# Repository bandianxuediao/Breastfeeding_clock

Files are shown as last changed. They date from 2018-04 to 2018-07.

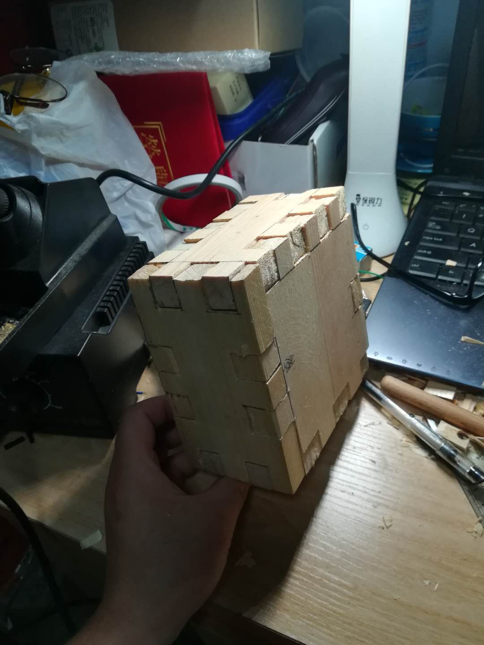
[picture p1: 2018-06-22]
DOC/Photos/15.jpg

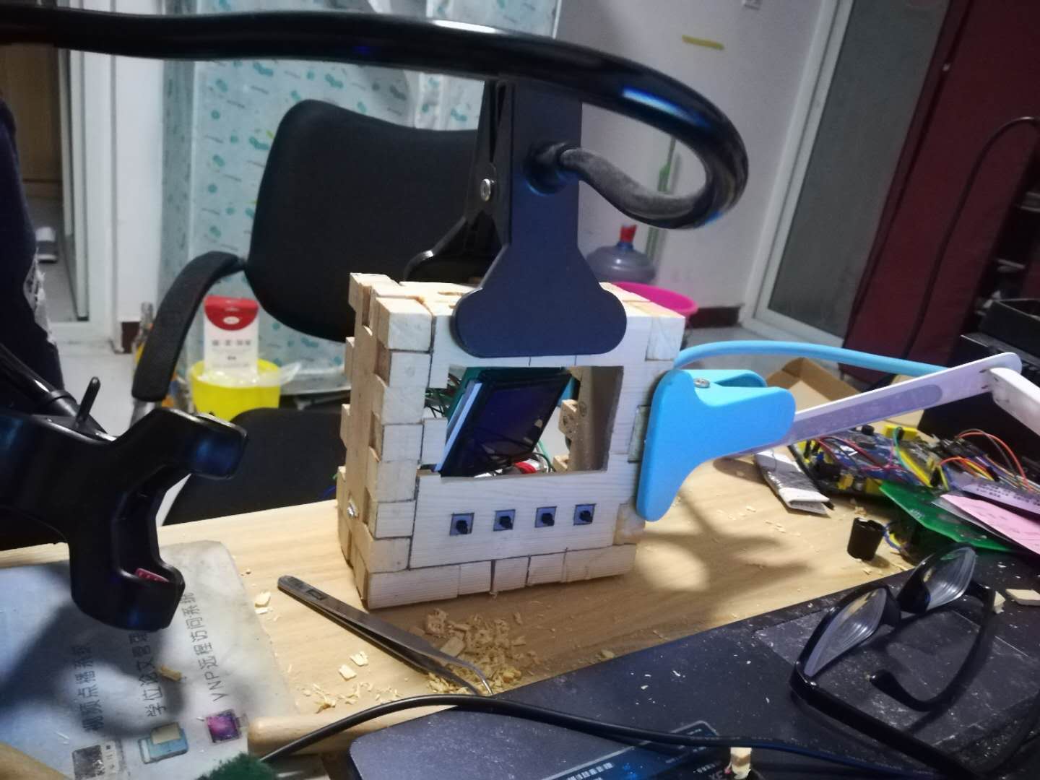
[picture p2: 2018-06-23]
DOC/Photos/10.jpg

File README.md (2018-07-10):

# Breastfeeding_clock<br/>
[开发过程记录](https://github.com/bandianxuediao/Breastfeeding_clock/blob/master/project_process.md)<br/>
详细的开发过程请点击上面的链接，或者直接访问project_process.md<br/>
更丰富的内容请访问我的个人网站[文禾每](http://www.wenhemei.com)<br/>
哺乳记录器，记录宝宝的哺乳时间，大小便时间、补水时间，以及距离上次相关事件的时间间隔。<br/>

## 项目背景
　　“丁酉年 冬月 癸巳日 卯时，爱妻诞下吾儿，重斤七整，性温良，状安详。及彼时新年初阳将醒，万物复苏。”这是我在2018年1月1日宝宝出生当天发表的朋友圈，而后妻子便开始了她照顾宝宝的忙碌生活。<br/>
　　数日之后，妻子提议：能不能做个软件来方便记录宝宝大小便和哺乳的时间。<br/>
　　本来想着只做一个android应用，方便随时使用手机来做记录、查看历史。后面我又觉得如果只做一个android应用的话之后就会被忘掉，随着时间的流逝什么也留不下来。干脆自己做一个实物的吧，于是便有了这个东西。<br/>
　　没有合适的工具，所有的隼都是使用雕刻刀一刀一刀刻出来的（还好当时买了较软的松木板，否则就不仅仅只是几个刀口几个水泡的事儿了）。<br/>
**通过这件事情算是真正的从心底里承认了一句话“不能随便评判别人的工作难易程度”。在预言阶段我仅仅是想拿几块木板用胶水粘起来，或者用钉子钉起来；采购物料期间看到淘宝推荐的雕刻刀，心想何不来几个卯榫，而且看起来也很简单。<br/>
实施阶段在我调整新打的PCB的时候我还在想着做个盒子也就一天的工作量。对，不出你们所料，做这个木盒子比画板子+写代码用的时间还长，而且还是如此的~不好看，"(￣▽￣)"""。<br/>**
　　从此项目的GitHub推进流程文档可以看出，项目建立时间是3月28日。中间还插入了其他的事情，不过6月总算是初步完成了。具体的项目推进流程可以在GitHub查看我的project_process.md文档。<br/>
## 项目介绍
　　简单介绍一下操作：<br/>
　　开机进入主界面后按下左按键进入项目列表，项目列表列出（哺乳、补水、小便、大便）项目；按上下键选择需要记录或查看的项目，按左键进入选中项目列表；列表中详细列出一共记录了多少条记录，距离上次记录过去了多少小时，按上下键翻页列表，按左按键增加一条当前时间的新记录（每个项目都有超时时间，在超时时间之内不允许再次存储此项目）。<br/>
　　主界面按下右按键可以进入时间设置的菜单，此处有时钟设置功能。同样是按上下键调整时间。<br/>
该记录器使用6000ma电池供电，红外对管检测物体靠近会点亮屏幕2分钟，其他任何按键均能触发1分钟倒计时重载。<br/>
## 硬件概述
　　硬件上面倒没什么复杂的：主控芯片使用的是STM32F103C8T6；12864的主控是ST7920；存储器使用了AT24CM01（1M位的EEPROM）；红外感应使用的是红外对管+LM393比较器。<br/>
### ST7920主控的12864<br/>
　　我这块12864不知道怎么回事，屏幕刷新几次就会出现乱码。之前用的同一批屏幕都没有这种情况，因为只剩下了一块，就只能先勉强用着。网上说可能驱动能力不足，于是加了上拉电阻4.7k-10k均没有效果；也有说时序不对，我是用逻辑分析仪抓的波形是没问题的；也有说在写屏幕的数据时没有控制好数据长度，这一条我还是有点赞同的，查了很久也没找到能出问题的地方，后边的项目结束后还的回头过来再解决一下。<br/>
　　原本怀疑的电源经过测试已经排除。  
　　乱码问题已经解决，是我之前已经遇到的但是却没引起我注意的一个bug。查出来之后才恍然大悟，我在RTC秒中断里面调用了屏幕刷新函数，而屏幕刷新函数里面有延时。所以**中断里面一定不能有延时**
### EEPROM的空间分配<br/>
#define INDEX_ADDR_LACTATION     10//哺乳索引存储地址<br/>
#define INDEX_ADDR_DRINK     20//补水索引存储地址<br/>
#define INDEX_ADDR_SHIT      30//大便索引存储地址<br/>
#define INDEX_ADDR_URINATE       40//小便索引存储地址<br/>
#define BASE_ADDR_LACTATION     100//哺乳存储的起始地址<br/>
#define BASE_ADDR_DRINK     30100//补水存储的起始地址<br/>
#define BASE_ADDR_SHIT      60100//大便存储的起始地址<br/>
#define BASE_ADDR_URINATE       90100//小便存储的起始地址<br/>
　　我的存储信息每条占用6个字节，假设每个项目每天存储6条，能够一直使用833天。如果以后有朋友需要定做的话可以更换flash来作为存储器，这样存个十几年是没问题的，^_^~~<br/>

### 红外感应<br/>
　　红外这块初步设计时准备使用热释电来做的，调试过程中发现热释电的感应范围太大了，远远超过了我的需求。经过吴哥的点拨，更换热释电为红外对管。直接淘宝5块钱包邮买了两个红外对管+LM393的模块，上机测试后完全符合我的预期效果，只是太阳光也对这东西有影响。以后如果还做的话这个也是一个需要着手解决的问题。<br/>

　　做板子的时候几个地方都是板子回来以后后期处理的，这些问题点我会在下一版本中修复。<br/>
　　V2完美版正在开发中……<br/>

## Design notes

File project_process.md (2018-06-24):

# Breastfeeding_clock<br/>
哺乳记录器，记录宝宝的哺乳时间，大小便时间、补水时间，以及距离上次相关事件的时间间隔。<br/>
# 开发过程记录

>2018年3月29日23:33<br/>
 >>使用储物柜的源代码，调通PA0-PA7作为12864的数据线；增加资料，主要是红外感应的资料；修改引脚分配表；DXP文件定义一些引脚。<br/>
 
>2018年3月31日23:00<br/>
>>关于电源这方面，之前没有做过电源的升压电路，也为安全考虑不敢轻易尝试。所以在淘宝购买了现成的充电宝的升压电路板，有过压过流保护，可以放心使用。<br/>
>>连接稳压电源时USB_5V负责给主板供电、给电池充电；<br/>
>>没有连接外部电源时，开关拨到电池供电端，此时就由电池给主板提供5V电源。<br/>
  
>2018年4月1日（补）<br/>
>>元件选择封装，错误检查，PCB布局。<br/>

>2018年4月2日23:30<br/>
>>修改部分元器件封装，修改原理图（将一些不确定，不需要插座的元件做成PIN1、空置引脚全部引出）<br/>
>>PB2(BOOT1)接地。<br/>
>>PCB电源布线、12864布线。<br/>

>2018年4月17日20：00<br/>
>>前面这段时间确定了PCB，并且打了样板。在老家焊接并初步调试完成。<br/>
>>之前准备采用热释电红外作为感应模组，通过对手头现成的热释电红外模块（BISS0001）的测试发现其感应范围太大，不适合做近距离的感应。<br/>
>>经同事点拨，红外对管似乎更适合我的需求。<br/>
>>使用明哥的寻迹小车上的红外对管测试之后发现确实能很好的满足我的需求，遂淘宝下单买了两个红外对管模块--抱愧一对红外对管，一个LM393比较器。<br/>

>2018年4月18日22：50
>>由于之前预留的micro usb接口需要飞线，并且暂时用不到串口下载功能，故没有使用CH340。今天将CH340电路中的一个NPN三极管的电路改造成了12864的背光电源开关，由单片机的PA15引脚控制。代码已经实现相关功能。等红外对管收到之后可以配合红外对管对12864的背光电源进行管理，达到降低功耗的目的。
>>这部分电路回头做在DXP里，第二版的时候再搞一下。

>2018年4月21日0：50（21日发现bug）
>>将正点原子的实时时钟相关代码移植过来，并进行相关测试。中间发现秒更新放在秒中断里面的话屏幕上会出现一些乱码，随着时间的推移会越来越多。网上不少人讲是时序的问题，但是我的12864驱动已经使用很长时间，所以不会存在时序不对的问题。单步测试后发现时间更新显示函数自带的屏幕刷新功能影响了显示，具体原因未知，屏蔽此函数内的屏幕刷新功能之后显示正常。<br/>
增加“查看”之后的二级界面（暂时不会MD的表格功能，回头补）<br/>

>2018年4月21日18:06
>>今日凌晨所调试的屏幕刷新出现乱码，是因为频繁的刷新导致的。遂将主循环中的刷新函数去掉，放在秒中断中进行刷新。<br/>
另,频繁刷新导致乱码的问题可能是因为ST7920相关引脚没有做外部上拉，导致单片机操作上拉速度跟不上，电压还没达到要求就已经开始进行数据传输，导致出频繁刷新出现乱码。【此问题可在下次打板时留下测试电路，以供验证本次猜测。】已经使用1K电阻验证，行不通。可能是电阻太小，导致电流过大，各管脚出现串联现象？未知，待验证。

>2018年4月22日23:32
>>今日对EEPROM空间的使用进行了划分，由于后面要更换更大的AT24CM01，所以给各个Item设置了一个Base_Address,后面只需要更改基地址就行。第五字节存储一个0x55，用作初始化判断；10、20、30、40起始位置之后的十个字节存储索引，实际只用两个字节存储当前已经存了几条信息。<br/>
      偏移计算：    索引信息X6(每条信息所占空间)+Base_Address【会做表的时候再来添加，信息都在笔记本上写着。】<br/>
>>今日还将流程走到显示列表的界面，发现有些之前没考虑到的问题。时间差的计算倒腾了一下午，各种伪代码写了三大页。晚饭后还是把之前的所有方案全部推翻了，三百多行的代码直接删掉。如果有运行速度更快、占用空间更小的方案出现，那之前的代码写的再漂亮也会在新方案出来的那一刻变成一堆一文不值的乱码。主要是因为之前考虑的不定因素太多了，导致代码不好编写。其实真是的需求、使用环境中并不会出现那些不定因素，因为其他代码也对不定因素进行了限制。<br/>

>2018年4月23日23:26
>>使用10K排阻上拉12864的数据线，经过测试还是有些效果的。回头功能完成之后再将其他引脚也使用10K电阻拉高，以提升其驱动能力。<br/>
再次推翻之前的时间差计算方式，使用一个基准时间，计算秒数来对比。省去计算负数的可能。

>2018年4月24日23:59
>>今天有点过头了，距离项目结束越来越近，人越显得兴奋。每个功能的逐步完善，均能够给自己带来极大的愉悦感。<br/>
完善时间差的计算函数、完善存储函数、编写列表刷新函数。***睡觉啦***

>2018年4月25日23:59
>>列表刷新函数功能有些混乱，未完成正常的列表移动显示功能。基础算法和指针的移动没有协调好，初步判断为指针在某一步的时候反向移动导致出现问题。反应在显示屏上是时间列表在某一步排序反了。**睡觉啦**

>2018年4月26日23:29
>>将AT24C02更换为AT24CM01,存储空间由16KB扩大为128KB。128KB=131072字节=0x20000字节。程序中的P0位就是最高的那半个字节2，启示表达起来就是0x19999右移16位之后的0x01，所以P0位只有两种状态，就是0和1.<br/>
准备再次奋战列表功能的时候发现屏幕突然暗了，测量之后发现电池电压只有2.4V了，充电几分钟之后变成2.58V。证明了电池的欠压保护还是起到了作用的，电池还能继续使用。功能模块完成以后可以考虑添加分压电阻，接上STM32引脚来测量电池电量。就这样了，收拾东西，明天晚上回家了。**睡觉啦**

>2018年5月4日
>>前面这些天回了趟老家，项目进展稍有延迟。<br/>
不过延迟并不代表没有什么都没有做，这期间将列表上下翻页的算法彻底的搞了一下，经过测试还算比较稳定的.<br/>
修改了计算时间差的一个小BUG，出现这个bug的原因是在计算时间差小数的时候忽略了秒计数的累加超过小时的情况，以至于会出现3600秒本来是1.0小时，结果计算为**1.10小时**这种情况。将小数位直接 %10就解决问题<br/>
对连续记录时间进行了限制，即在上次记录之后多长时间内不应该再次产生该事件的防错机制。<br/>
初步设定的时间:<br/>
哺乳：1小时<br/>
补水：1小时<br/>
小便：0.5小时<br/>
大便：1小时<br/>
这个时间我本来是给每一个事件设定了一个计数器，后来实际Debug过程中发现直接拿前面算好的时间差是更方便的。所以一个项目中如果不去认真考虑的话会产生很多垃圾代码，上位机体现可能不是很明显，但嵌入式开发过程中就会出现各种问题，最常见的就是存储空间不够了，垃圾代码过多，僵尸代码不及时处理会拖慢系统的运行效率，也给阅读代码的人带来很大的阻碍。**严格审查代码**切记切记！<br/>
4号这天将红外对管控制显示屏背光的相关代码进行了添加。<br/>
具体功能为：<br/>
1、开机背光亮起2分钟<br/>
2、任何按键都能唤醒背光2分钟<br/>
3、红外触发背光亮起2分钟<br/>
启示我考虑的是将12864的主电源也接在一起，这两天将代码完善之后可以实际测试一下。<br/>
另外12864来回按键出现乱码的问题依然存在，这是一个遗留的大问题，后面还需要尝试各种操作：重新焊线，热熔胶固定焊接头等等....<br/>

>2018年5月6日 19:33
>>从昨天一直到现在中间基本上把程序固定了，昨晚开始弄直隼。下手之前觉得没什么，可一旦开始动手便感觉到了困难。所以说各行各业都有各自的运行轨迹，不能再没有任何尝试抑或浅尝之后便断定这东西很简单，很好搞。实际动手操作过才能下结论。好了不写了，得抓紧时间干活了，这两天我才吃了两顿饭。一直觉得时间不够用，恨不得一天二十四小时都在干活。刚刚短信提示TTP229的板子快递到了，待会明哥回来吃过饭后把板子焊接完毕再睡觉咯。

>2018年5月25日
>>前面这段时间一直在弄木盒子，越弄越发现真不不好搞。今天上班时想到了屏幕乱码是不是电源引起的呢？经过给显示屏单独供电测试之后发现问题不在电源。所以后面还是得把寻找问题的重点放在屏幕底层驱动上面～

>2018年6月6日23:16
>>今天发现是RTC秒中断里面的SHOWTIME函数导致出现乱码的，一瞬间想起来之前也发现了这个问题，但是没有引起我的重视。今天仔细一想，还真是这里的问题。因为showtime函数里面有屏幕刷新函数，而屏幕刷新函数里面又带有延时函数。在中断里面调用延时函数是一大忌讳，我已经在这上面吃了几次亏了。虽然这次只有几微秒的延时，但还是搞得自己差点崩溃，不过好在最后的最后还是被细心的我找到了问题所在（hiahiahiahia^_^）。</br>

>>其实，把刷新函数放在住循环里面处理的话也有问题。就是每一个秒中断不能及时的被显示出来。这就会导致在主界面上面看到秒计数一会儿快一会儿慢。</br>
>>一个问题解决之后就得想着另一个问题了，一个是主界面秒计数（这个不解决也行，优先级靠后）；在一个就是电量消耗的问题。今天更新的版本中我已经

将屏幕持续点亮的时间从两分钟降低到了1分钟，以此来节约电量。再者再完善过列表显示的逻辑之后再继续测试功耗的大小。说到列表显示就再多说几句，列

表显示之前是已经测试过没问题了的，这两天发现还是有一点小bug的，不知道是代码没有保存还是怎么的。明天再详细的看一下吧。**睡觉了，安安**

>2018年6月7日22:36
>>昨天发现列表显示还是有点问题，今天查了下代码发现一点bug，修改之后初步测试通过。

>2018年6月11日00:36
>>测试了功耗，将万用表串联在升压电路之后到主板之间的线路上测得：屏幕亮起的时候124.8mA；屏幕灭掉的时候74mA。升压电路还有损耗，所以估算使用时长约为60H.
>>精修木盒，将不平整的契合部分使用木挫修平整，使用木屑填充小缝隙，木片填充大缝隙，使用502固定，等待502干了之后再挫一遍。

>2018年6月15日 23:33
>>今天使用小型平锉将契合部分锉了一下，然后发到木工论坛。有师傅说还可以继续打磨，抛光一下。</br>

>2018年6月17日 23:45
>>今天使用吊磨，套上80目的砂带狠狠地打磨了一下。将之前开的榫的差距给补了一点，看起来不是坑坑洼洼的了。木板厚一些还是有好处的，这次差不多磨掉了3mm左右。明天是用砂纸稍微抛光一下看看。</br>

>2018年6月18日
>使用砂纸打磨到1000目，时间比较紧，没有继续打磨。网上买了蜂蜡也没到，所以暂时没有烫蜡。

>2018年6月21日
>>功能补全，因为之前测试的时候一直都是拿哺乳这一项来进行的，其他项没有相关的流程代码，今天把其他三项的流程代码添加了上来。并且在菜单项里面添加了清空的功能，经过初步测试是没有什么问题的。

>2018年6月24日
>>今天把屏幕持续点亮时间从之前限定的2分钟缩短为1分钟了，省电为主。况且任何操作都会重置倒计时，所以不用担心操作时间不够的问题。</br>

##到此为止，此项目基本完结。后面如果再有更新也只是日志文档的完整，与项目具体内容无关。</br>
　　　　　　　　　　　　　　　　　　　　　　　　　　　　　——2018年6月24日   李亚东

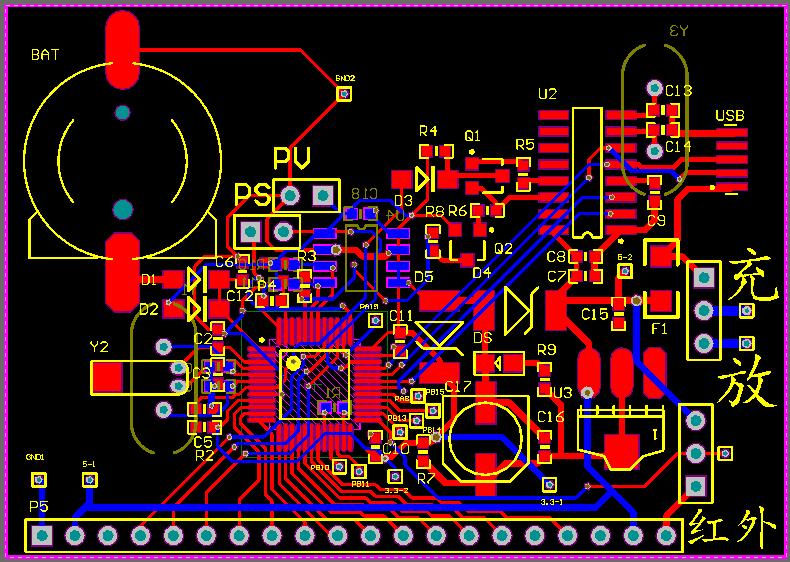
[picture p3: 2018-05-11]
DOC/Photos/PCB.jpg

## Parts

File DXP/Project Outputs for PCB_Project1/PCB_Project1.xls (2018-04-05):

Comment | Designator | Footprint | Quantity
BATT | BAT | BATM | 1
22P | C1, C2, C3, C4, C13, C14 | 0603p | 6
104 | C5, C7, C9, C10, C11, C12, C15, C16, C18，'C6 | 0603p | 9
10uF | C8 | 0603p | 1
220uF | C17 | CC6.56.5 | 1
1N4148 | D1, D2, D3 | DIODE_SOP | 3
SMBJ5.0A | D4, D5 | SMBJ | 2
LED1 | DS | SMDLED | 1
1000mA | F1 | 1206 | 1
OLED | P5 | HDR1X20 | 1
S8050 | Q1 | SOT-23R | 1
S8550 | Q2 | SOT-23R | 1
0 | R1, R7 | 0603p | 2
10K | R2, R3, R4 | 0603p | 3
1K | R5, R6, R8 | 0603p | 3
510 | R9 | 0603p | 1
4.7K | R10, R11 | 0603P | 2
STM32F103CBT6 | U1 | LQFP48_M | 1
CH340G | U2 | SOP16M | 1
AMS1117-3.3 | U3 | AMS1117 | 1
24C02 | U4 | SOP-8 | 1
USB | USB | USB/SM0.8-6H5 | 1
8M | Y1 | XTAL_US | 1
32.768K | Y2 | XTAL32 | 1
12MHz | Y3 | XTAL_US | 1

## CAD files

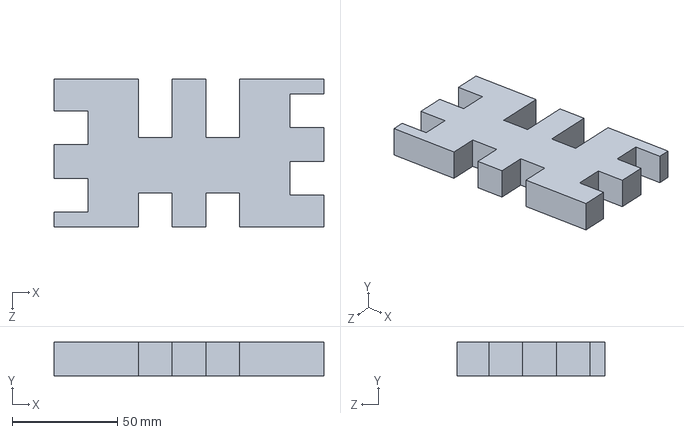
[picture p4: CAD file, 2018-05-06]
DOC/SOLIDWORKS/零件3.SLDPRT
128.0 x 16.0 x 70.0 mm

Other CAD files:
DOC/SOLIDWORKS/零件1.SLDPRT
DOC/SOLIDWORKS/零件2.SLDPRT

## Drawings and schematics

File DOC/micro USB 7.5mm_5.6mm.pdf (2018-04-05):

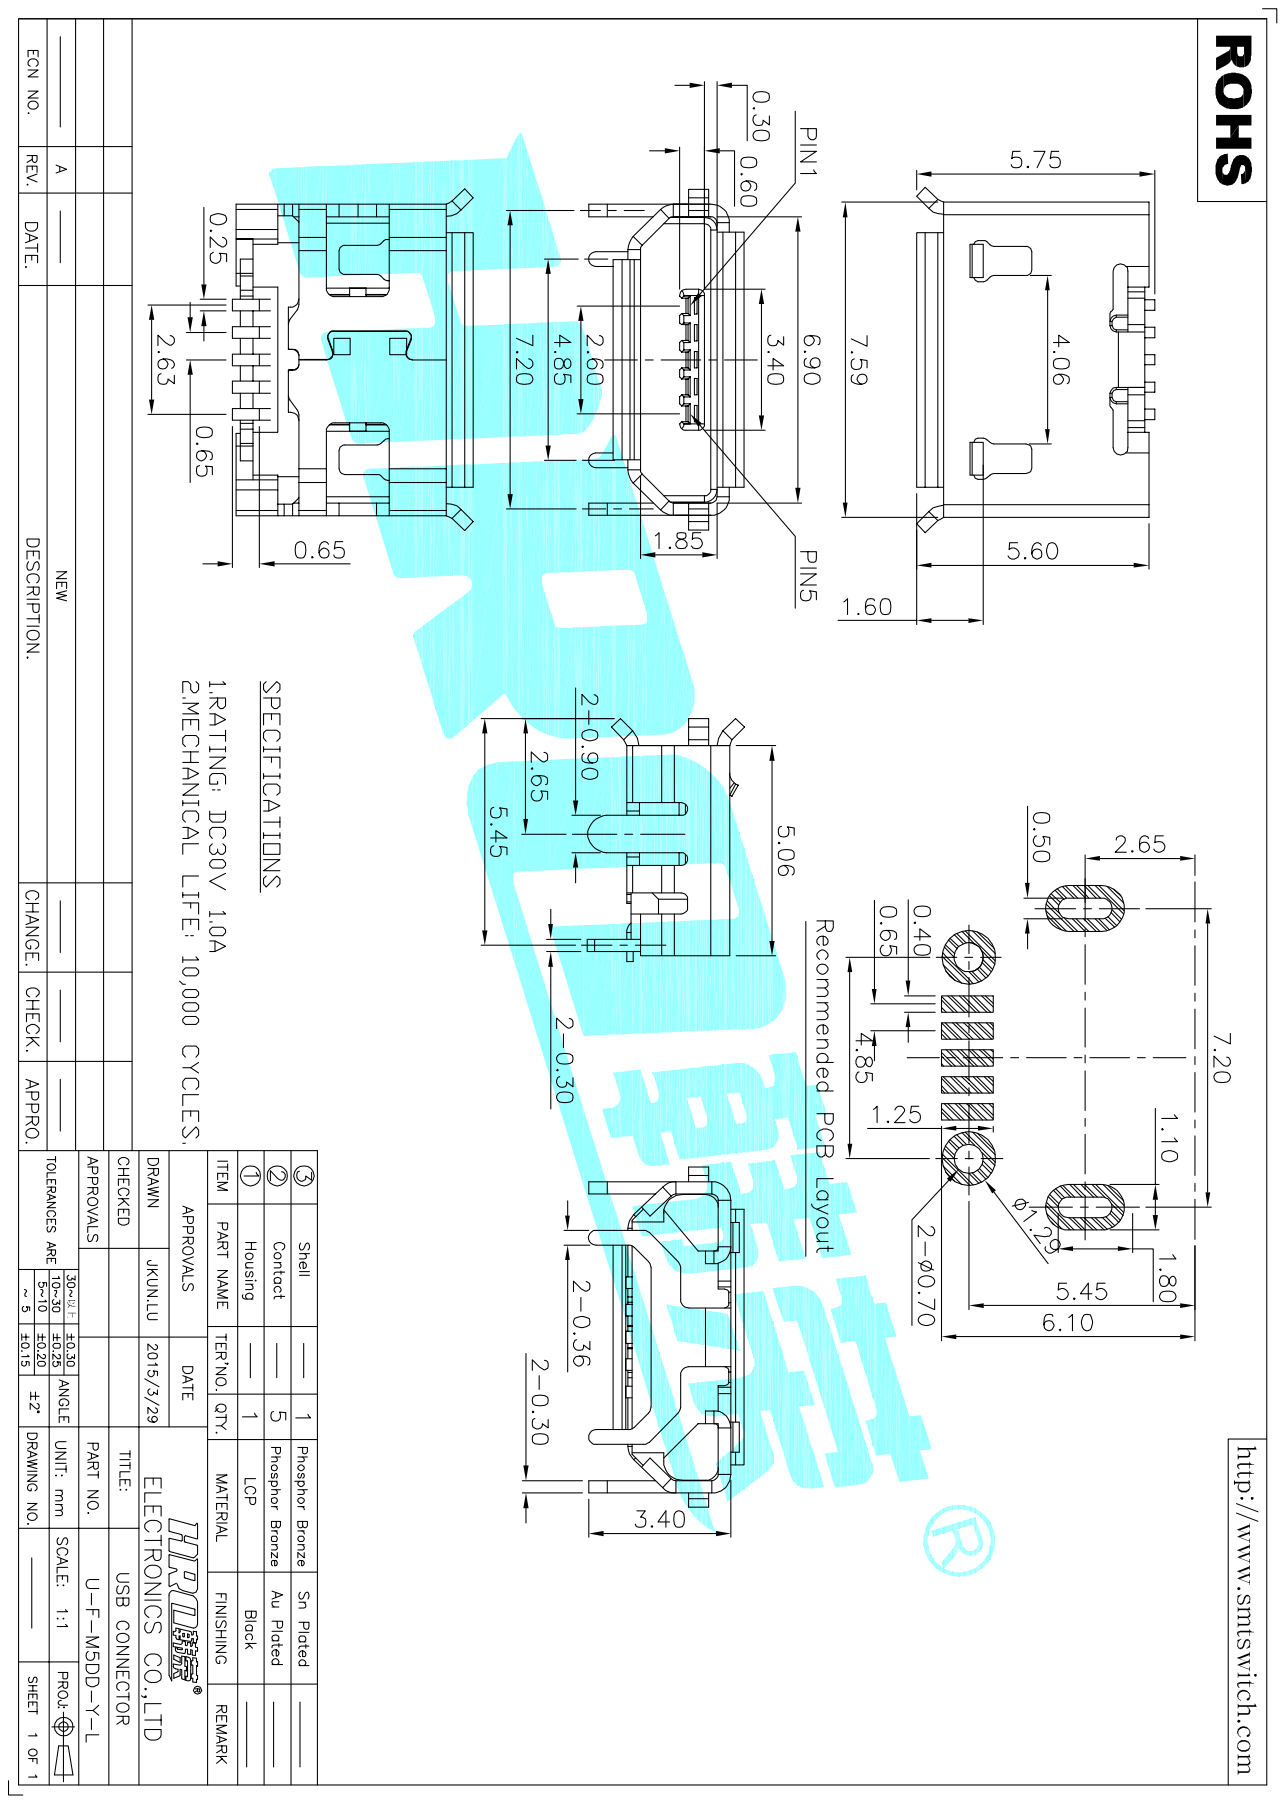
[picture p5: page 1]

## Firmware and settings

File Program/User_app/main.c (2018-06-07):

#include "includes.h"
SYS_STATE Current_state;
SYS_STATE KEY_state;
int main(void)
{
	u8 temp = 0;
	u8 read_temp1[6];
	//  NVIC_SetVectorTable(NVIC_VectTab_FLASH, 0x20000); //与配置文件相对应  配置程序的起始地址，前面一部分留给了bootload
	NVIC_PriorityGroupConfig(NVIC_PriorityGroup_2); //设置NVIC中断分组2:2位抢占优先级，2位响应优先级

	SysTickInit();         //设置滴答定时器中断时间为1ms

	EE_IIC_Init();             //EEPROM的IIC初始化

	RCC_APB2PeriphClockCmd(RCC_APB2Periph_AFIO, ENABLE);
	GPIO_PinRemapConfig(GPIO_Remap_SWJ_JTAGDisable, ENABLE);        //使用了spi3，禁用JATG，保留SWD功能

	PIN_Init();

	lcd12864_init();//12864初始化
	RTC_Init();
	ShowWelcome();
	delay_ms(600);
	Back_Light(1);//开机背光电源输出5V
	SetLightTimer(60000);//设置背光亮起时间1分钟
	Current_state = WELCOME_WAIT;



	//  Back_Light(0);
	//RTC_Set(2018, 4, 24, 23, 26, 30); //设置时间
	//          AT24CXX_WriteLenByte(10, 0,2);
	//          AT24CXX_WriteLenByte(20, 0,2);
	//          AT24CXX_WriteLenByte(30,0, 2);
	//          AT24CXX_WriteLenByte(40,0, 2);



	oled_updatescr(0, 64);//屏幕刷新

	//  //测试一下，一直刷新屏幕，清空缓存是否还会出现乱码现象
	//  while(1)
	//  {
	//

	//          oled_updatescr(0, 64);     //屏幕刷新
	//      delay_ms(10);

	//  }



	while(1)
	{
		Detect_Pin_State();

		if(GetLightTimerState() == TIME_OUT)
		{
			Back_Light(0);//背光电源关闭输出5V
		}

		White_Line();

		//      if(max_waite==10000)
		//      {   lcdreset();                    //初始化LCD屏
		//              clrgdram();
		//              max_waite=0;
		//      }

		oled_updatescr(0, 64);       //屏幕刷新
	}
}

/************* The End ! *****************/

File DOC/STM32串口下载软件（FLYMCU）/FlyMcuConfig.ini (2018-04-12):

[Comm]
Port=-1
PortBps=0
[FileSetting]
chkbReloadFile=1
FileName=D:\LYD\WorkSpace\GitHub\Breastfeeding_clock\Program\USER\obj\cabinet.hex
PageControl1Index=1
N2Checked=1
language=0
[LPCSetting]
LastSuccessBps=460800
OscFreq=20000
rgLpcEraseAllBlock=1
rgLpc1FC=0
cbISPEN_WDT=0
[STMSetting]
cbSTMExecAfterFlash=1
cbVerify=1
cbRtsDtrUsage->ItemIndex=3
MenuUseEagleComm=0
menuBeepEnable=0
menuEnableHighBps=0
menuUseRamIsp=0
cbAutoProgram=0
cbSTMWriteOption=0
STMOptionBytes=A5FFFFFFFFFFFFFF
STM32F2_F4OptionBytes=AAFFFFF
[FormWindow]
WindowState=0
WindowXDPI=96
WindowYDPI=96
WindowClientHeight96=373
WindowClientWidth96=680
WindowLeft96=353
WindowTop96=139
[fmSerialNoSetting]
cbUseID=0
medAddress=0x08000000
medLength=16
medInit=4
medIncLen=1
rgEndian=0
rgSnInFlashOrEeprom=0
cbSerialNoFormat=0
[fmSerialization]
cbEnableSerialization=0
edMcuIspDllFileName=
[fmProgCount]
medProgCount=0
[fmMSP430Settings]
orgVecs=FFFFFFFFFFFFFFFFFFFFFFFFFFFFFFFFFFFFFFFFFFFFFFFFFFFFFFFFFFFFFFFF
Vecs=FFFFFFFFFFFFFFFFFFFFFFFFFFFFFFFFFFFFFFFFFFFFFFFFFFFFFFFFFFFFFFFFFFFFFFFFFFFFFFFFFFFFFFFFFFFFFFFFFFFFFFFFFFFFFFFFFFFFFFFFFFFFFFFF
BSLKeys=FFFFFFFFFFFFFFFFFFFFFFFFFFFFFFFFFFFFFFFFFFFFFFFFFFFFFFFFFFFFFFFFFFFFFFFFFFFFFFFFFFFFFFFFFFFFFFFFFFFFFFFFFFFFFFFFFFFFFFFFFFFFFFFFFFFFFFFFFFFFFFFFFFFFFFFFFFFFFFFFFFFFFFFFFFFFFFFFFFFFFFFFFFFFFFFF
PortSettings=1
MiscSettings=0
cbEnableAdvanceVectorModify=0

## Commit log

2018-03-28 创建DXP文件
    原理图基本完成，还差按键没有添加，功能引脚未完全分配。
    [PCB1.PcbDoc, PCB_Project1.PrjPCB, Sheet1.SchDoc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]
2018-03-28 doc
    引脚分配表
    [IO引脚分配表.xlsx]
2018-03-29 网络搜集ST7920例程
    以前用的ST7920驱动部分代码使用寄存器操作，显得有些混乱。从网上查找的例程，代码看起来比较正规，等待回家测试合并~~
2018-03-29 变更源代码
    使用储物柜的源代码，调通PA0-PA7作为12864的数据线；增加资料，主要是红外感应的资料；修改引脚分配表；DXP文件定义一些引脚。
    [IO引脚分配表.xlsx, PCB_Project1.PrjPCB, Sheet1.SchDoc]
2018-03-31 修改原理图
    修改原理图
    [PCB_Project1.PrjPCB, Sheet1.SchDoc]
2018-04-01 生成PCB、布局
    生成PCB，并完成布局
    [PCB1.PcbDoc, PCB_Project1.PrjPCB, Sheet1.SchDoc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]
2018-04-02 修改原理图、布线
    修改原理图、布线、调整部分引脚
    [IO引脚分配表.xlsx, PCB_Project1.PrjPCB, Sheet1.SchDoc]
2018-04-03 layout
    layout
    [PCB_Project1.PrjPCB]
2018-04-05 BOM记录
    [PCB_Project1.xls]
2018-04-05 Mini usb准备更换为micro usb
    Mini usb准备更换为micro usb
    [PCB_Project1.xls]
2018-04-05 修改代码
    将12864引脚暂时使用开发板的能用的引脚；
    将原来储物柜的代码精简，修改。
2018-04-07 layout complete
    layout complete
    [PCB1.PcbLib, PCB_Project1.PrjPCB, PCB_Project1.SCHLIB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]
2018-04-11 精简程序
    将以前储物柜的代码简化
2018-04-15 外部中断
    外部中断红外~验证未通过，感应距离太长
2018-04-16 解决一个警告
    解决一个警告
2018-04-17 外部中断服务函数名
    外部中断服务函数名
2018-04-17 格式化代码
    格式化代码
2018-04-17 主框架搭建
    案件检测，循环事件框架基本搭建完毕。
2018-04-18 尝试修改MD格式
    刚开始学习编辑MD格式
2018-04-18 MD格式测试
2018-04-18 添加4月18号的工作内容
2018-04-18 4月18开发记录
    由于之前预留的micro usb接口需要飞线，并且暂时用不到串口下载功能，故没有使用CH340。今天将CH340电路中的一个NPN三极管的电路改造成了12864的背光电源开关，由单片机的PA15引脚控制。代码已经实现相关功能。等红外对管收到之后可以配合红外对管对12864的背光电源进行管理，达到降低功耗的目的。 这部分电路回头做在DXP里，第二版的时候再搞一下。
2018-04-19 删除hex
    删除hex
2018-04-20 储物柜的RTC代码
    储物柜的RTC代码
2018-04-20 RTC时钟系统
    移植正点原子RTC时钟系统，修改显示部分，增加下一级操作
2018-04-20 更新4月20日晚项目进展
2018-04-21 今日凌晨所调试的屏幕刷新出现乱码，是因为频繁的刷新导致的。
    今日凌晨所调试的屏幕刷新出现乱码，是因为频繁的刷新导致的。遂将主循环中的刷新函数去掉，放在秒中断中进行刷新。<br/>
    另,频繁刷新导致乱码的问题可能是因为ST7920相关引脚没有做外部上拉，导致单片机操作上拉速度跟不上，电压还没达到要求就已经开始进行数据传输，导致出频繁刷新出现乱码。【此问题可在下次打板时留下测试电路，以供验证本次猜测。】
2018-04-21 测试目录功能
    失败
2018-04-22 界面流程、存储
    界面流程走到列表显示这一步；
    存储空间划分完成；
    计算时间差有多种算法，先备份未完成的，正在写更简便的。
2018-04-22 修改计算时间差算法
    修改计算时间差算法；
    列表界面调整
2018-04-22 4月22日项目进展
    详见MD文件
2018-04-22 格式调整
2018-04-23 修改功能函数
    修改读索引函数、添加字体、添加其他项目流程、添加写函数（未完成）
2018-04-24 修改时间差计算函数
    时间差对比基础时间，算秒差
2018-04-24 存储、读取、刷新列表
    存储、读取、刷新列表函数的修改及完善。
    均未完成，测试中
2018-04-24 补充4月23日项目进展
2018-04-24 4月24日项目进展
2018-04-24 时间写错了
2018-04-25 时间差计算函数完善
    时间差计算函数完善
    [the infrared sensors.OBJ]
2018-04-25 将开发过程记录转移
2018-04-25 将开发过程转移到project_process.md
2018-04-25 修改格式，添加个人网址
2018-04-25 修改外部网址
2018-04-25 修改https为http
2018-04-25 列表刷新函数修改
    列表刷新功能有些混乱，未调整完。
2018-04-25 更新4月25日项目进展
2018-04-26 更换eeprom
    更换eeprom，修改相关代码并测试
2018-04-26 更换EEPROM,修改相关代码
2018-04-27 修改错别字
2018-04-29 修改延时函数
2018-05-02 列表显示调整
    调整列表显示代码，功能正常，性能不完善。健壮性还需增强。
2018-05-03 5月3日修改
    1、修正时间差显示BUG
    2、列表小修
    3、限制记录时间间隔添加
    4、显示菜单
    [MidFunction.c, MidFunction.h, display.h]
2018-05-04 红外控制背光
    添加红外控制背光相关代码：
    1、开机背光亮起2分钟
    2、任何按键都能唤醒背光2分钟
    3、红外触发背光亮起2分钟
2018-05-05 添加4月26日到5月4日之间的项目推进情况
2018-05-05 完善功能
    1、修复列表显示BUG(存储少于3条不显示)
    2、添加时间修改功能
    3、完善哺乳之外的其他功能
    [MidFunction.c, MidFunction.h, ST7920.c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]
2018-05-06 5月6日项目进展
2018-05-11 添加PCB截图
2018-05-15 测试插入图片
2018-05-15 test insert photo
2018-05-15 test MD
    MD文件编辑测试
2018-05-15 文档，准备写在网站的内容
2018-05-16 编辑MD文件
    添加项目总结（虽然还没结束~~）
2018-05-16 文档修改
    已经添加到readme
2018-05-23 12864乱码问题查找
2018-05-25 5月26日，电源测试
2018-06-03 will test if updatescr can to give rise to display error
    [main.c]
2018-06-05 LED 刷新代码微调
2018-06-06 solve error display problem
    1、today i find the show_time();cause display error problem;and solve it when move the refresh function to main.
    2、in order to save power ,reduce the wait time to 1min.
    [MidFunction.c, main.c]
2018-06-06 更新2018年6月6日项目进展
2018-06-07 修改列表刷新功能
    在哺乳功能下修改列表刷新功能，初步测试通过。
2018-06-07 项目进展
2018-06-10 整理目录结构
    [PCB_Project1.PrjPCB, Sheet1.SchDoc]
2018-06-10 6月10号进展（11号更新）
2018-06-17 add process 17
    16日周六，在家陪宝宝了。17日回到北京出租屋继续打磨
2018-06-18 6月18砂纸打磨
2018-06-19 添加图片，用于网站编辑
2018-06-20 添加外观图，用于网站编辑
2018-06-21 补全功能
    1、补全哺乳之外的三个列表功能
    2、添加清空功能
2018-06-21 6月21日 功能项补全
    1、功能项补全
    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
2018-06-22 盒体制作图片，编辑项目介绍使用
2018-06-23 盒体打胶固定图片，网站编辑使用
2018-06-23 内部图，网站编辑使用
2018-06-24 屏幕熄灭时间减小为1分钟
2018-06-24 项目完结
    ##到此为止，此项目基本完结。后面如果再有更新也只是日志文档的完整，与项目具体内容无关。</br>
    ——2018年6月24日 李亚东
2018-06-27 gif文件
2018-07-10 格式修改，语法错误修改，准备移到博客。
